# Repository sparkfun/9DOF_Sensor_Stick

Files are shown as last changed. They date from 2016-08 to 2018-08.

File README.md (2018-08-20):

SparkFun 9 Degrees of Freedom - Sensor Stick
=============================================

SparkFun 9 Degrees of Freedom - Sensor Stick

[*SparkFun 9 Degrees of Freedom - Sensor Stick (SEN-13944)*](https://www.sparkfun.com/products/13944)

The SparkFun 9DOF Sensor Stick is a very small sensor board with 9 degrees of freedom.
It includes the LSM9DS1 with a simple I2C interface and a mounting hole for attaching it to your project.
Also, the board is a mere 0.9" in length, 0.4" in width, and 0.036" thick (0.093" overall), allowing it to be easily mounted in just about any application.
 
 Repository Contents
-------------------
* **/Hardware** - All Eagle design files (.brd, .sch)

Documentation
--------------

* **[Installing an Arduino Library Guide](https://learn.sparkfun.com/tutorials/installing-an-arduino-library)** - Basic information on how to install an Arduino library.
* **[Library](https://github.com/sparkfun/SparkFun_LSM9DS1_Arduino_Library)** - Arduino library for the 9DoF Sensor Stick.
* **[Hookup Guide](https://learn.sparkfun.com/tutorials/9dof-sensor-stick-hookup-guide)** - Basic hookup guide for the 9DoF Sensor Stick.
 
License Information
-------------------
The hardware is released under [Creative Commons ShareAlike 4.0 International](https://creativecommons.org/licenses/by-sa/4.0/).
The code is beerware; if you see me (or any other SparkFun employee) at the local, and you've found our code helpful, please buy us a round!

Distributed as-is; no warranty is given.

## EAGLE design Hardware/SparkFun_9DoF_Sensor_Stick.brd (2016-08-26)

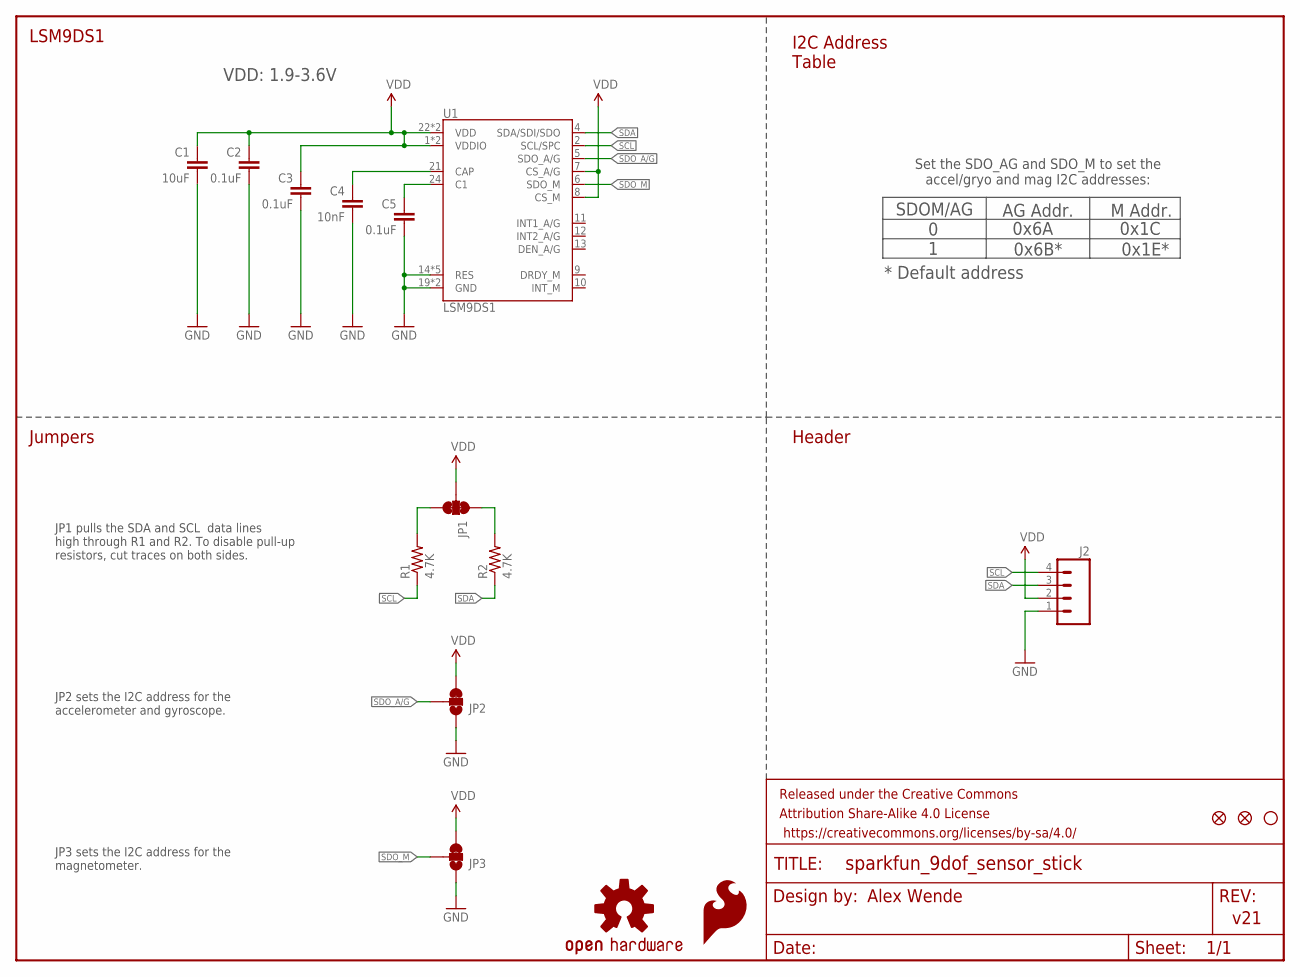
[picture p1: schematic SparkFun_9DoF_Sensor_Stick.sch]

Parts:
C1: 10uF; 0603-CAP
C2, C3, C5: 0.1uF; 0603-CAP
C4: 10nF; 0603-CAP
FD3, FD4: FIDUCIALUFIDUCIAL; MICRO-FIDUCIAL
FRAME1: FRAME-LETTER; CREATIVE_COMMONS
H1: STAND-OFF
J2: M04NO_SILK_ALL_ROUND; 1X04_NO_SILK_ALL_ROUND
JP1: JUMPER-PAD-3-NC_BY_TRACE; PAD-JUMPER-3-3OF3_NC_BY_TRACE_YES_SILK_FULL_BOX
JP2, JP3: JUMPER-PAD-3-2OF3_NC_BY_TRACE_SMALL; PAD-JUMPER-3-2OF3_NC_BY_TRACE_YES_SILK_FULL_BOX
LOGO1: SFE_LOGO_FLAME.1_INCH; SFE_LOGO_FLAME_.1
LOGO3: OSHW-LOGOMINI; OSHW-LOGO-MINI
R1, R2: 4.7K; 0603-RES
U1: LSM9DS1; LGA24-8X4

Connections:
GND: C1.2, C2.2, C3.2, C4.2, C5.2, J2.1, JP2.1, JP3.1, U1.14 (RES), U1.15 (RES), U1.16 (RES), U1.17 (RES), U1.18 (RES), U1.19 (GND), U1.20 (GND)
unnamed: JP1.1, R2.2
unnamed: JP1.3, R1.2
unnamed: C4.1, U1.21 (CAP)
unnamed: C5.1, U1.24 (C1)
SCL: J2.4, R1.1, U1.2 (SCL/SPC)
SDA: J2.3, R2.1, U1.4 (SDA/SDI/SDO)
SDO_A/G: JP2.2, U1.5 (SDO_A/G)
SDO_M: JP3.2, U1.6 (SDO_M)
VDD: C1.1, C2.1, C3.1, J2.2, JP1.2, JP2.3, JP3.3, U1.1 (VDDIO), U1.3 (VDDIO), U1.7 (CS_A/G), U1.8 (CS_M), U1.22 (VDD), U1.23 (VDD)

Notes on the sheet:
Alex Wende
v21
LSM9DS1
SDOM/AG
AG Addr.
0 1
M Addr.
Set the SDO_AG and SDO_M to set the accel/gryo and mag I2C addresses:
I2C Address Table
Header
Jumpers
JP1 pulls the SDA and SCL data lines high through R1 and R2. To disable pull-up resistors, cut traces on both sides.
JP2 sets the I2C address for the accelerometer and gyroscope.
JP3 sets the I2C address for the magnetometer.
0x6A
0x6B*
0x1C
0x1E*
* Default address
VDD: 1.9-3.6V

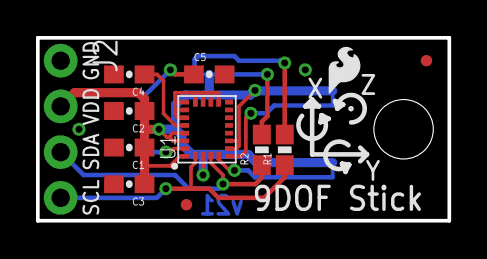
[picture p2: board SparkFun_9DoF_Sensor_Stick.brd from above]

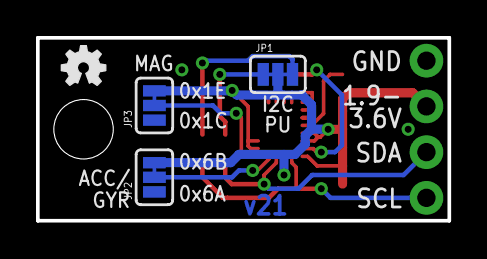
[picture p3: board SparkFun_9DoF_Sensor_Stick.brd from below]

Board: 2 copper layers, 22.9 x 10.2 mm, 18 parts (4 on the bottom side), 10 nets.

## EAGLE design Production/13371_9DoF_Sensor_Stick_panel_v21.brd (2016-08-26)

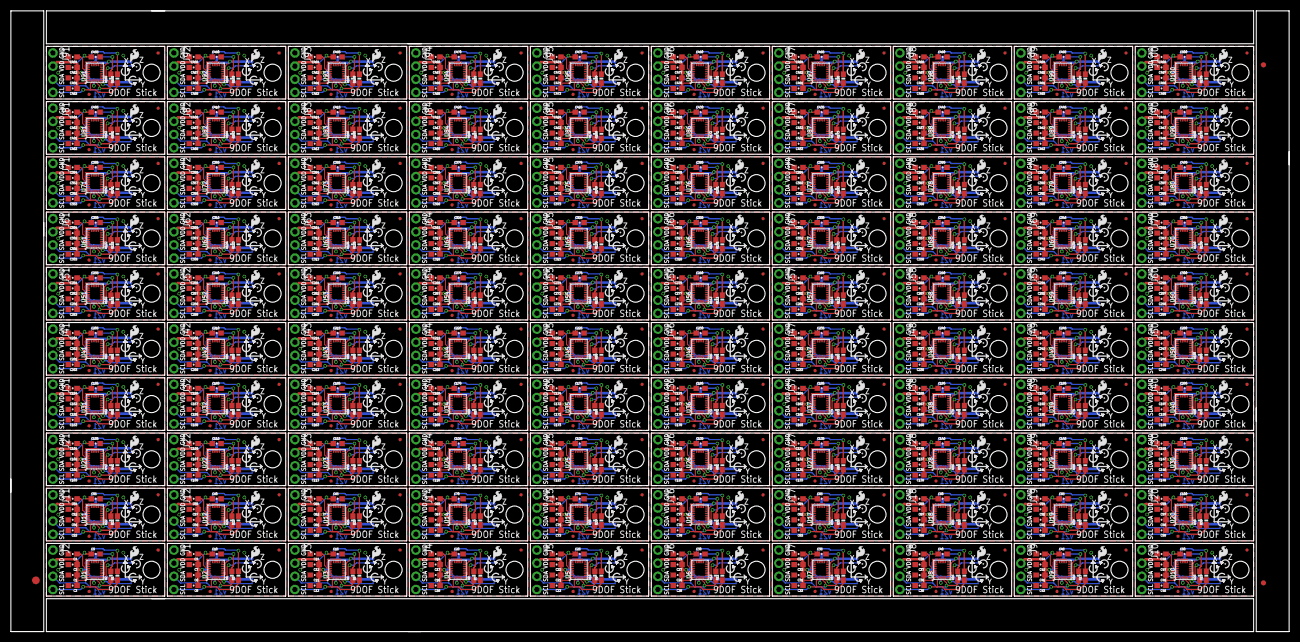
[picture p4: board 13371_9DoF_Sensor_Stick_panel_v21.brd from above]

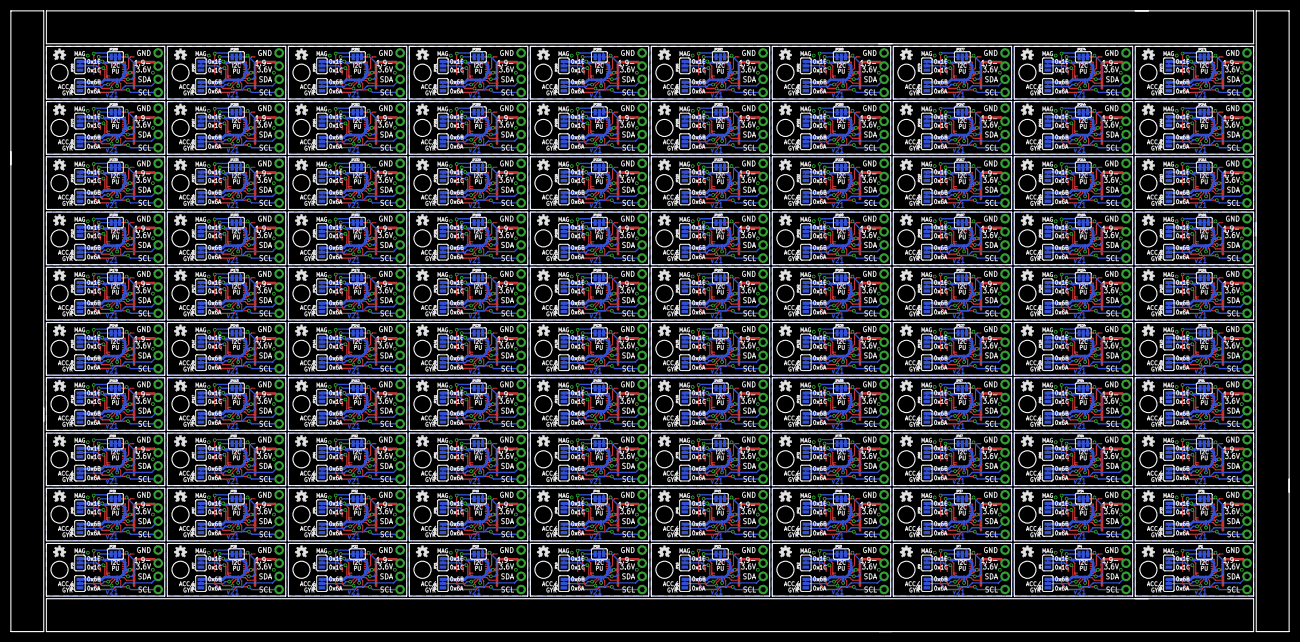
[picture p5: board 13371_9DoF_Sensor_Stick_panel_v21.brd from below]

Board: 2 copper layers, 246.9 x 119.9 mm, 1703 parts (400 on the bottom side), 1000 nets.

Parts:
C1, C6, C11, C16, C21, C26, C31, C36, C41, C46, C51, C56, C61, C66, C71, C76, C81, C86, C91, C96, C101, C106, C111, C116, C121, C126, C131, C136, C141, C146, C151, C156, C161, C166, C171, C176, C181, C186, C191, C196, C201, C206, C211, C216, C221, C226, C231, C236, C241, C246, C251, C256, C261, C266, C271, C276, C281, C286, C291, C296, C301, C306, C311, C316, C321, C326, C331, C336, C341, C346, C351, C356, C361, C366, C371, C376, C381, C386, C391, C396, C401, C406, C411, C416, C421, C426, C431, C436, C441, C446, C451, C456, C461, C466, C471, C476, C481, C486, C491, C496: 10uF; 0603-CAP
C2, C3, C5, C7, C8, C10, C12, C13, C15, C17, C18, C20, C22, C23, C25, C27, C28, C30, C32, C33, C35, C37, C38, C40, C42, C43, C45, C47, C48, C50, C52, C53, C55, C57, C58, C60, C62, C63, C65, C67, C68, C70, C72, C73, C75, C77, C78, C80, C82, C83, C85, C87, C88, C90, C92, C93, C95, C97, C98, C100, C102, C103, C105, C107, C108, C110, C112, C113, C115, C117, C118, C120, C122, C123, C125, C127, C128, C130, C132, C133, C135, C137, C138, C140, C142, C143, C145, C147, C148, C150, C152, C153, C155, C157, C158, C160, C162, C163, C165, C167, C168, C170, C172, C173, C175, C177, C178, C180, C182, C183, C185, C187, C188, C190, C192, C193, C195, C197, C198, C200, C202, C203, C205, C207, C208, C210, C212, C213, C215, C217, C218, C220, C222, C223, C225, C227, C228, C230, C232, C233, C235, C237, C238, C240, C242, C243, C245, C247, C248, C250, C252, C253, C255, C257, C258, C260, C262, C263, C265, C267, C268, C270, C272, C273, C275, C277, C278, C280, C282, C283, C285, C287, C288, C290, C292, C293, C295, C297, C298, C300, C302, C303, C305, C307, C308, C310, C312, C313, C315, C317, C318, C320, C322, C323, C325, C327, C328, C330, C332, C333, C335, C337, C338, C340, C342, C343, C345, C347, C348, C350, C352, C353, C355, C357, C358, C360, C362, C363, C365, C367, C368, C370, C372, C373, C375, C377, C378, C380, C382, C383, C385, C387, C388, C390, C392, C393, C395, C397, C398, C400, C402, C403, C405, C407, C408, C410, C412, C413, C415, C417, C418, C420, C422, C423, C425, C427, C428, C430, C432, C433, C435, C437, C438, C440, C442, C443, C445, C447, C448, C450, C452, C453, C455, C457, C458, C460, C462, C463, C465, C467, C468, C470, C472, C473, C475, C477, C478, C480, C482, C483, C485, C487, C488, C490, C492, C493, C495, C497, C498, C500: 0.1uF; 0603-CAP
C4, C9, C14, C19, C24, C29, C34, C39, C44, C49, C54, C59, C64, C69, C74, C79, C84, C89, C94, C99, C104, C109, C114, C119, C124, C129, C134, C139, C144, C149, C154, C159, C164, C169, C174, C179, C184, C189, C194, C199, C204, C209, C214, C219, C224, C229, C234, C239, C244, C249, C254, C259, C264, C269, C274, C279, C284, C289, C294, C299, C304, C309, C314, C319, C324, C329, C334, C339, C344, C349, C354, C359, C364, C369, C374, C379, C384, C389, C394, C399, C404, C409, C414, C419, C424, C429, C434, C439, C444, C449, C454, C459, C464, C469, C474, C479, C484, C489, C494, C499: 10nF; 0603-CAP
E$1: FIDUCIAL-1.5X3
E$7, E$8: FIDUCIAL-1X2
FD1, FD2, FD3, FD4, FD5, FD6, FD7, FD8, FD9, FD10, FD11, FD12, FD13, FD14, FD15, FD16, FD17, FD18, FD19, FD20, FD21, FD22, FD23, FD24, FD25, FD26, FD27, FD28, FD29, FD30, FD31, FD32, FD33, FD34, FD35, FD36, FD37, FD38, FD39, FD40, FD41, FD42, FD43, FD44, FD45, FD46, FD47, FD48, FD49, FD50, FD51, FD52, FD53, FD54, FD55, FD56, FD57, FD58, FD59, FD60, FD61, FD62, FD63, FD64, FD65, FD66, FD67, FD68, FD69, FD70, FD71, FD72, FD73, FD74, FD75, FD76, FD77, FD78, FD79, FD80, FD81, FD82, FD83, FD84, FD85, FD86, FD87, FD88, FD89, FD90, FD91, FD92, FD93, FD94, FD95, FD96, FD97, FD98, FD99, FD100, FD101, FD102, FD103, FD104, FD105, FD106, FD107, FD108, FD109, FD110, FD111, FD112, FD113, FD114, FD115, FD116, FD117, FD118, FD119, FD120, FD121, FD122, FD123, FD124, FD125, FD126, FD127, FD128, FD129, FD130, FD131, FD132, FD133, FD134, FD135, FD136, FD137, FD138, FD139, FD140, FD141, FD142, FD143, FD144, FD145, FD146, FD147, FD148, FD149, FD150, FD151, FD152, FD153, FD154, FD155, FD156, FD157, FD158, FD159, FD160, FD161, FD162, FD163, FD164, FD165, FD166, FD167, FD168, FD169, FD170, FD171, FD172, FD173, FD174, FD175, FD176, FD177, FD178, FD179, FD180, FD181, FD182, FD183, FD184, FD185, FD186, FD187, FD188, FD189, FD190, FD191, FD192, FD193, FD194, FD195, FD196, FD197, FD198, FD199, FD200: FIDUCIALUFIDUCIAL; MICRO-FIDUCIAL
H1, H2, H3, H4, H5, H6, H7, H8, H9, H10, H11, H12, H13, H14, H15, H16, H17, H18, H19, H20, H21, H22, H23, H24, H25, H26, H27, H28, H29, H30, H31, H32, H33, H34, H35, H36, H37, H38, H39, H40, H41, H42, H43, H44, H45, H46, H47, H48, H49, H50, H51, H52, H53, H54, H55, H56, H57, H58, H59, H60, H61, H62, H63, H64, H65, H66, H67, H68, H69, H70, H71, H72, H73, H74, H75, H76, H77, H78, H79, H80, H81, H82, H83, H84, H85, H86, H87, H88, H89, H90, H91, H92, H93, H94, H95, H96, H97, H98, H99, H100: STAND-OFF
J1, J2, J3, J4, J5, J6, J7, J8, J9, J10, J11, J12, J13, J14, J15, J16, J17, J18, J19, J20, J21, J22, J23, J24, J25, J26, J27, J28, J29, J30, J31, J32, J33, J34, J35, J36, J37, J38, J39, J40, J41, J42, J43, J44, J45, J46, J47, J48, J49, J50, J51, J52, J53, J54, J55, J56, J57, J58, J59, J60, J61, J62, J63, J64, J65, J66, J67, J68, J69, J70, J71, J72, J73, J74, J75, J76, J77, J78, J79, J80, J81, J82, J83, J84, J85, J86, J87, J88, J89, J90, J91, J92, J93, J94, J95, J96, J97, J98, J99, J100: 1X04_NO_SILK_ALL_ROUND
JP1, JP4, JP7, JP10, JP13, JP16, JP19, JP22, JP25, JP28, JP31, JP34, JP37, JP40, JP43, JP46, JP49, JP52, JP55, JP58, JP61, JP64, JP67, JP70, JP73, JP76, JP79, JP82, JP85, JP88, JP91, JP94, JP97, JP100, JP103, JP106, JP109, JP112, JP115, JP118, JP121, JP124, JP127, JP130, JP133, JP136, JP139, JP142, JP145, JP148, JP151, JP154, JP157, JP160, JP163, JP166, JP169, JP172, JP175, JP178, JP181, JP184, JP187, JP190, JP193, JP196, JP199, JP202, JP205, JP208, JP211, JP214, JP217, JP220, JP223, JP226, JP229, JP232, JP235, JP238, JP241, JP244, JP247, JP250, JP253, JP256, JP259, JP262, JP265, JP268, JP271, JP274, JP277, JP280, JP283, JP286, JP289, JP292, JP295, JP298: PAD-JUMPER-3-3OF3_NC_BY_TRACE_YES_SILK_FULL_BOX
JP2, JP3, JP5, JP6, JP8, JP9, JP11, JP12, JP14, JP15, JP17, JP18, JP20, JP21, JP23, JP24, JP26, JP27, JP29, JP30, JP32, JP33, JP35, JP36, JP38, JP39, JP41, JP42, JP44, JP45, JP47, JP48, JP50, JP51, JP53, JP54, JP56, JP57, JP59, JP60, JP62, JP63, JP65, JP66, JP68, JP69, JP71, JP72, JP74, JP75, JP77, JP78, JP80, JP81, JP83, JP84, JP86, JP87, JP89, JP90, JP92, JP93, JP95, JP96, JP98, JP99, JP101, JP102, JP104, JP105, JP107, JP108, JP110, JP111, JP113, JP114, JP116, JP117, JP119, JP120, JP122, JP123, JP125, JP126, JP128, JP129, JP131, JP132, JP134, JP135, JP137, JP138, JP140, JP141, JP143, JP144, JP146, JP147, JP149, JP150, JP152, JP153, JP155, JP156, JP158, JP159, JP161, JP162, JP164, JP165, JP167, JP168, JP170, JP171, JP173, JP174, JP176, JP177, JP179, JP180, JP182, JP183, JP185, JP186, JP188, JP189, JP191, JP192, JP194, JP195, JP197, JP198, JP200, JP201, JP203, JP204, JP206, JP207, JP209, JP210, JP212, JP213, JP215, JP216, JP218, JP219, JP221, JP222, JP224, JP225, JP227, JP228, JP230, JP231, JP233, JP234, JP236, JP237, JP239, JP240, JP242, JP243, JP245, JP246, JP248, JP249, JP251, JP252, JP254, JP255, JP257, JP258, JP260, JP261, JP263, JP264, JP266, JP267, JP269, JP270, JP272, JP273, JP275, JP276, JP278, JP279, JP281, JP282, JP284, JP285, JP287, JP288, JP290, JP291, JP293, JP294, JP296, JP297, JP299, JP300: PAD-JUMPER-3-2OF3_NC_BY_TRACE_YES_SILK_FULL_BOX
LOGO1, LOGO2, LOGO5, LOGO7, LOGO9, LOGO11, LOGO13, LOGO15, LOGO17, LOGO19, LOGO21, LOGO23, LOGO25, LOGO27, LOGO29, LOGO31, LOGO33, LOGO35, LOGO37, LOGO39, LOGO41, LOGO43, LOGO45, LOGO47, LOGO49, LOGO51, LOGO53, LOGO55, LOGO57, LOGO59, LOGO61, LOGO63, LOGO65, LOGO67, LOGO69, LOGO71, LOGO73, LOGO75, LOGO77, LOGO79, LOGO81, LOGO83, LOGO85, LOGO87, LOGO89, LOGO91, LOGO93, LOGO95, LOGO97, LOGO99, LOGO101, LOGO103, LOGO105, LOGO107, LOGO109, LOGO111, LOGO113, LOGO115, LOGO117, LOGO119, LOGO121, LOGO123, LOGO125, LOGO127, LOGO129, LOGO131, LOGO133, LOGO135, LOGO137, LOGO139, LOGO141, LOGO143, LOGO145, LOGO147, LOGO149, LOGO151, LOGO153, LOGO155, LOGO157, LOGO159, LOGO161, LOGO163, LOGO165, LOGO167, LOGO169, LOGO171, LOGO173, LOGO175, LOGO177, LOGO179, LOGO181, LOGO183, LOGO185, LOGO187, LOGO189, LOGO191, LOGO193, LOGO195, LOGO197, LOGO199: SFE_LOGO_FLAME.1_INCH; SFE_LOGO_FLAME_.1
LOGO3, LOGO4, LOGO6, LOGO8, LOGO10, LOGO12, LOGO14, LOGO16, LOGO18, LOGO20, LOGO22, LOGO24, LOGO26, LOGO28, LOGO30, LOGO32, LOGO34, LOGO36, LOGO38, LOGO40, LOGO42, LOGO44, LOGO46, LOGO48, LOGO50, LOGO52, LOGO54, LOGO56, LOGO58, LOGO60, LOGO62, LOGO64, LOGO66, LOGO68, LOGO70, LOGO72, LOGO74, LOGO76, LOGO78, LOGO80, LOGO82, LOGO84, LOGO86, LOGO88, LOGO90, LOGO92, LOGO94, LOGO96, LOGO98, LOGO100, LOGO102, LOGO104, LOGO106, LOGO108, LOGO110, LOGO112, LOGO114, LOGO116, LOGO118, LOGO120, LOGO122, LOGO124, LOGO126, LOGO128, LOGO130, LOGO132, LOGO134, LOGO136, LOGO138, LOGO140, LOGO142, LOGO144, LOGO146, LOGO148, LOGO150, LOGO152, LOGO154, LOGO156, LOGO158, LOGO160, LOGO162, LOGO164, LOGO166, LOGO168, LOGO170, LOGO172, LOGO174, LOGO176, LOGO178, LOGO180, LOGO182, LOGO184, LOGO186, LOGO188, LOGO190, LOGO192, LOGO194, LOGO196, LOGO198, LOGO200: OSHW-LOGOMINI; OSHW-LOGO-MINI
R1, R2, R3, R4, R5, R6, R7, R8, R9, R10, R11, R12, R13, R14, R15, R16, R17, R18, R19, R20, R21, R22, R23, R24, R25, R26, R27, R28, R29, R30, R31, R32, R33, R34, R35, R36, R37, R38, R39, R40, R41, R42, R43, R44, R45, R46, R47, R48, R49, R50, R51, R52, R53, R54, R55, R56, R57, R58, R59, R60, R61, R62, R63, R64, R65, R66, R67, R68, R69, R70, R71, R72, R73, R74, R75, R76, R77, R78, R79, R80, R81, R82, R83, R84, R85, R86, R87, R88, R89, R90, R91, R92, R93, R94, R95, R96, R97, R98, R99, R100, R101, R102, R103, R104, R105, R106, R107, R108, R109, R110, R111, R112, R113, R114, R115, R116, R117, R118, R119, R120, R121, R122, R123, R124, R125, R126, R127, R128, R129, R130, R131, R132, R133, R134, R135, R136, R137, R138, R139, R140, R141, R142, R143, R144, R145, R146, R147, R148, R149, R150, R151, R152, R153, R154, R155, R156, R157, R158, R159, R160, R161, R162, R163, R164, R165, R166, R167, R168, R169, R170, R171, R172, R173, R174, R175, R176, R177, R178, R179, R180, R181, R182, R183, R184, R185, R186, R187, R188, R189, R190, R191, R192, R193, R194, R195, R196, R197, R198, R199, R200: 4.7K; 0603-RES
U1, U2, U3, U4, U5, U6, U7, U8, U9, U10, U11, U12, U13, U14, U15, U16, U17, U18, U19, U20, U21, U22, U23, U24, U25, U26, U27, U28, U29, U30, U31, U32, U33, U34, U35, U36, U37, U38, U39, U40, U41, U42, U43, U44, U45, U46, U47, U48, U49, U50, U51, U52, U53, U54, U55, U56, U57, U58, U59, U60, U61, U62, U63, U64, U65, U66, U67, U68, U69, U70, U71, U72, U73, U74, U75, U76, U77, U78, U79, U80, U81, U82, U83, U84, U85, U86, U87, U88, U89, U90, U91, U92, U93, U94, U95, U96, U97, U98, U99, U100: LSM9DS1; LGA24-8X4

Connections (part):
GND: C1.2, C2.2, C3.2, C4.2, C5.2, J2.1, JP2.1, JP3.1, U1.14, U1.15, U1.16, U1.17, U1.18, U1.19, U1.20
GND1: C6.2, C7.2, C8.2, C9.2, C10.2, J1.1, JP5.1, JP6.1, U2.14, U2.15, U2.16, U2.17, U2.18, U2.19, U2.20
GND2: C11.2, C12.2, C13.2, C14.2, C15.2, J3.1, JP8.1, JP9.1, U3.14, U3.15, U3.16, U3.17, U3.18, U3.19, U3.20
GND3: C16.2, C17.2, C18.2, C19.2, C20.2, J4.1, JP11.1, JP12.1, U4.14, U4.15, U4.16, U4.17, U4.18, U4.19, U4.20
GND4: C21.2, C22.2, C23.2, C24.2, C25.2, J5.1, JP14.1, JP15.1, U5.14, U5.15, U5.16, U5.17, U5.18, U5.19, U5.20
GND5: C26.2, C27.2, C28.2, C29.2, C30.2, J6.1, JP17.1, JP18.1, U6.14, U6.15, U6.16, U6.17, U6.18, U6.19, U6.20
GND6: C31.2, C32.2, C33.2, C34.2, C35.2, J7.1, JP20.1, JP21.1, U7.14, U7.15, U7.16, U7.17, U7.18, U7.19, U7.20
GND7: C36.2, C37.2, C38.2, C39.2, C40.2, J8.1, JP23.1, JP24.1, U8.14, U8.15, U8.16, U8.17, U8.18, U8.19, U8.20
GND8: C41.2, C42.2, C43.2, C44.2, C45.2, J9.1, JP26.1, JP27.1, U9.14, U9.15, U9.16, U9.17, U9.18, U9.19, U9.20
GND9: C46.2, C47.2, C48.2, C49.2, C50.2, J10.1, JP29.1, JP30.1, U10.14, U10.15, U10.16, U10.17, U10.18, U10.19, U10.20
GND10: C51.2, C52.2, C53.2, C54.2, C55.2, J11.1, JP32.1, JP33.1, U11.14, U11.15, U11.16, U11.17, U11.18, U11.19, U11.20
GND11: C56.2, C57.2, C58.2, C59.2, C60.2, J12.1, JP35.1, JP36.1, U12.14, U12.15, U12.16, U12.17, U12.18, U12.19, U12.20
GND12: C61.2, C62.2, C63.2, C64.2, C65.2, J13.1, JP38.1, JP39.1, U13.14, U13.15, U13.16, U13.17, U13.18, U13.19, U13.20
GND13: C66.2, C67.2, C68.2, C69.2, C70.2, J14.1, JP41.1, JP42.1, U14.14, U14.15, U14.16, U14.17, U14.18, U14.19, U14.20
GND14: C71.2, C72.2, C73.2, C74.2, C75.2, J15.1, JP44.1, JP45.1, U15.14, U15.15, U15.16, U15.17, U15.18, U15.19, U15.20
GND15: C76.2, C77.2, C78.2, C79.2, C80.2, J16.1, JP47.1, JP48.1, U16.14, U16.15, U16.16, U16.17, U16.18, U16.19, U16.20
GND16: C81.2, C82.2, C83.2, C84.2, C85.2, J17.1, JP50.1, JP51.1, U17.14, U17.15, U17.16, U17.17, U17.18, U17.19, U17.20
GND17: C86.2, C87.2, C88.2, C89.2, C90.2, J18.1, JP53.1, JP54.1, U18.14, U18.15, U18.16, U18.17, U18.18, U18.19, U18.20
GND18: C91.2, C92.2, C93.2, C94.2, C95.2, J19.1, JP56.1, JP57.1, U19.14, U19.15, U19.16, U19.17, U19.18, U19.19, U19.20
GND19: C96.2, C97.2, C98.2, C99.2, C100.2, J20.1, JP59.1, JP60.1, U20.14, U20.15, U20.16, U20.17, U20.18, U20.19, U20.20
GND20: C101.2, C102.2, C103.2, C104.2, C105.2, J21.1, JP62.1, JP63.1, U21.14, U21.15, U21.16, U21.17, U21.18, U21.19, U21.20
GND21: C106.2, C107.2, C108.2, C109.2, C110.2, J22.1, JP65.1, JP66.1, U22.14, U22.15, U22.16, U22.17, U22.18, U22.19, U22.20
GND22: C111.2, C112.2, C113.2, C114.2, C115.2, J23.1, JP68.1, JP69.1, U23.14, U23.15, U23.16, U23.17, U23.18, U23.19, U23.20
GND23: C116.2, C117.2, C118.2, C119.2, C120.2, J24.1, JP71.1, JP72.1, U24.14, U24.15, U24.16, U24.17, U24.18, U24.19, U24.20
GND24: C121.2, C122.2, C123.2, C124.2, C125.2, J25.1, JP74.1, JP75.1, U25.14, U25.15, U25.16, U25.17, U25.18, U25.19, U25.20
GND25: C126.2, C127.2, C128.2, C129.2, C130.2, J26.1, JP77.1, JP78.1, U26.14, U26.15, U26.16, U26.17, U26.18, U26.19, U26.20
GND26: C131.2, C132.2, C133.2, C134.2, C135.2, J27.1, JP80.1, JP81.1, U27.14, U27.15, U27.16, U27.17, U27.18, U27.19, U27.20
GND27: C136.2, C137.2, C138.2, C139.2, C140.2, J28.1, JP83.1, JP84.1, U28.14, U28.15, U28.16, U28.17, U28.18, U28.19, U28.20
GND28: C141.2, C142.2, C143.2, C144.2, C145.2, J29.1, JP86.1, JP87.1, U29.14, U29.15, U29.16, U29.17, U29.18, U29.19, U29.20
GND29: C146.2, C147.2, C148.2, C149.2, C150.2, J30.1, JP89.1, JP90.1, U30.14, U30.15, U30.16, U30.17, U30.18, U30.19, U30.20
GND30: C151.2, C152.2, C153.2, C154.2, C155.2, J31.1, JP92.1, JP93.1, U31.14, U31.15, U31.16, U31.17, U31.18, U31.19, U31.20
GND31: C156.2, C157.2, C158.2, C159.2, C160.2, J32.1, JP95.1, JP96.1, U32.14, U32.15, U32.16, U32.17, U32.18, U32.19, U32.20
GND32: C161.2, C162.2, C163.2, C164.2, C165.2, J33.1, JP98.1, JP99.1, U33.14, U33.15, U33.16, U33.17, U33.18, U33.19, U33.20
GND33: C166.2, C167.2, C168.2, C169.2, C170.2, J34.1, JP101.1, JP102.1, U34.14, U34.15, U34.16, U34.17, U34.18, U34.19, U34.20
GND34: C171.2, C172.2, C173.2, C174.2, C175.2, J35.1, JP104.1, JP105.1, U35.14, U35.15, U35.16, U35.17, U35.18, U35.19, U35.20
GND35: C176.2, C177.2, C178.2, C179.2, C180.2, J36.1, JP107.1, JP108.1, U36.14, U36.15, U36.16, U36.17, U36.18, U36.19, U36.20
GND36: C181.2, C182.2, C183.2, C184.2, C185.2, J37.1, JP110.1, JP111.1, U37.14, U37.15, U37.16, U37.17, U37.18, U37.19, U37.20
GND37: C186.2, C187.2, C188.2, C189.2, C190.2, J38.1, JP113.1, JP114.1, U38.14, U38.15, U38.16, U38.17, U38.18, U38.19, U38.20
GND38: C191.2, C192.2, C193.2, C194.2, C195.2, J39.1, JP116.1, JP117.1, U39.14, U39.15, U39.16, U39.17, U39.18, U39.19, U39.20
GND39: C196.2, C197.2, C198.2, C199.2, C200.2, J40.1, JP119.1, JP120.1, U40.14, U40.15, U40.16, U40.17, U40.18, U40.19, U40.20
GND40: C201.2, C202.2, C203.2, C204.2, C205.2, J41.1, JP122.1, JP123.1, U41.14, U41.15, U41.16, U41.17, U41.18, U41.19, U41.20
GND41: C206.2, C207.2, C208.2, C209.2, C210.2, J42.1, JP125.1, JP126.1, U42.14, U42.15, U42.16, U42.17, U42.18, U42.19, U42.20
GND42: C211.2, C212.2, C213.2, C214.2, C215.2, J43.1, JP128.1, JP129.1, U43.14, U43.15, U43.16, U43.17, U43.18, U43.19, U43.20
GND43: C216.2, C217.2, C218.2, C219.2, C220.2, J44.1, JP131.1, JP132.1, U44.14, U44.15, U44.16, U44.17, U44.18, U44.19, U44.20
GND44: C221.2, C222.2, C223.2, C224.2, C225.2, J45.1, JP134.1, JP135.1, U45.14, U45.15, U45.16, U45.17, U45.18, U45.19, U45.20
GND45: C226.2, C227.2, C228.2, C229.2, C230.2, J46.1, JP137.1, JP138.1, U46.14, U46.15, U46.16, U46.17, U46.18, U46.19, U46.20
GND46: C231.2, C232.2, C233.2, C234.2, C235.2, J47.1, JP140.1, JP141.1, U47.14, U47.15, U47.16, U47.17, U47.18, U47.19, U47.20
GND47: C236.2, C237.2, C238.2, C239.2, C240.2, J48.1, JP143.1, JP144.1, U48.14, U48.15, U48.16, U48.17, U48.18, U48.19, U48.20
GND48: C241.2, C242.2, C243.2, C244.2, C245.2, J49.1, JP146.1, JP147.1, U49.14, U49.15, U49.16, U49.17, U49.18, U49.19, U49.20
GND49: C246.2, C247.2, C248.2, C249.2, C250.2, J50.1, JP149.1, JP150.1, U50.14, U50.15, U50.16, U50.17, U50.18, U50.19, U50.20
GND50: C251.2, C252.2, C253.2, C254.2, C255.2, J51.1, JP152.1, JP153.1, U51.14, U51.15, U51.16, U51.17, U51.18, U51.19, U51.20
GND51: C256.2, C257.2, C258.2, C259.2, C260.2, J52.1, JP155.1, JP156.1, U52.14, U52.15, U52.16, U52.17, U52.18, U52.19, U52.20
GND52: C261.2, C262.2, C263.2, C264.2, C265.2, J53.1, JP158.1, JP159.1, U53.14, U53.15, U53.16, U53.17, U53.18, U53.19, U53.20
GND53: C266.2, C267.2, C268.2, C269.2, C270.2, J54.1, JP161.1, JP162.1, U54.14, U54.15, U54.16, U54.17, U54.18, U54.19, U54.20
GND54: C271.2, C272.2, C273.2, C274.2, C275.2, J55.1, JP164.1, JP165.1, U55.14, U55.15, U55.16, U55.17, U55.18, U55.19, U55.20
GND55: C276.2, C277.2, C278.2, C279.2, C280.2, J56.1, JP167.1, JP168.1, U56.14, U56.15, U56.16, U56.17, U56.18, U56.19, U56.20
GND56: C281.2, C282.2, C283.2, C284.2, C285.2, J57.1, JP170.1, JP171.1, U57.14, U57.15, U57.16, U57.17, U57.18, U57.19, U57.20
GND57: C286.2, C287.2, C288.2, C289.2, C290.2, J58.1, JP173.1, JP174.1, U58.14, U58.15, U58.16, U58.17, U58.18, U58.19, U58.20
GND58: C291.2, C292.2, C293.2, C294.2, C295.2, J59.1, JP176.1, JP177.1, U59.14, U59.15, U59.16, U59.17, U59.18, U59.19, U59.20
GND59: C296.2, C297.2, C298.2, C299.2, C300.2, J60.1, JP179.1, JP180.1, U60.14, U60.15, U60.16, U60.17, U60.18, U60.19, U60.20
GND60: C301.2, C302.2, C303.2, C304.2, C305.2, J61.1, JP182.1, JP183.1, U61.14, U61.15, U61.16, U61.17, U61.18, U61.19, U61.20
GND61: C306.2, C307.2, C308.2, C309.2, C310.2, J62.1, JP185.1, JP186.1, U62.14, U62.15, U62.16, U62.17, U62.18, U62.19, U62.20
GND62: C311.2, C312.2, C313.2, C314.2, C315.2, J63.1, JP188.1, JP189.1, U63.14, U63.15, U63.16, U63.17, U63.18, U63.19, U63.20
GND63: C316.2, C317.2, C318.2, C319.2, C320.2, J64.1, JP191.1, JP192.1, U64.14, U64.15, U64.16, U64.17, U64.18, U64.19, U64.20
GND64: C321.2, C322.2, C323.2, C324.2, C325.2, J65.1, JP194.1, JP195.1, U65.14, U65.15, U65.16, U65.17, U65.18, U65.19, U65.20
GND65: C326.2, C327.2, C328.2, C329.2, C330.2, J66.1, JP197.1, JP198.1, U66.14, U66.15, U66.16, U66.17, U66.18, U66.19, U66.20
GND66: C331.2, C332.2, C333.2, C334.2, C335.2, J67.1, JP200.1, JP201.1, U67.14, U67.15, U67.16, U67.17, U67.18, U67.19, U67.20
GND67: C336.2, C337.2, C338.2, C339.2, C340.2, J68.1, JP203.1, JP204.1, U68.14, U68.15, U68.16, U68.17, U68.18, U68.19, U68.20
GND68: C341.2, C342.2, C343.2, C344.2, C345.2, J69.1, JP206.1, JP207.1, U69.14, U69.15, U69.16, U69.17, U69.18, U69.19, U69.20
GND69: C346.2, C347.2, C348.2, C349.2, C350.2, J70.1, JP209.1, JP210.1, U70.14, U70.15, U70.16, U70.17, U70.18, U70.19, U70.20
GND70: C351.2, C352.2, C353.2, C354.2, C355.2, J71.1, JP212.1, JP213.1, U71.14, U71.15, U71.16, U71.17, U71.18, U71.19, U71.20
GND71: C356.2, C357.2, C358.2, C359.2, C360.2, J72.1, JP215.1, JP216.1, U72.14, U72.15, U72.16, U72.17, U72.18, U72.19, U72.20
GND72: C361.2, C362.2, C363.2, C364.2, C365.2, J73.1, JP218.1, JP219.1, U73.14, U73.15, U73.16, U73.17, U73.18, U73.19, U73.20
GND73: C366.2, C367.2, C368.2, C369.2, C370.2, J74.1, JP221.1, JP222.1, U74.14, U74.15, U74.16, U74.17, U74.18, U74.19, U74.20
GND74: C371.2, C372.2, C373.2, C374.2, C375.2, J75.1, JP224.1, JP225.1, U75.14, U75.15, U75.16, U75.17, U75.18, U75.19, U75.20
GND75: C376.2, C377.2, C378.2, C379.2, C380.2, J76.1, JP227.1, JP228.1, U76.14, U76.15, U76.16, U76.17, U76.18, U76.19, U76.20
GND76: C381.2, C382.2, C383.2, C384.2, C385.2, J77.1, JP230.1, JP231.1, U77.14, U77.15, U77.16, U77.17, U77.18, U77.19, U77.20
GND77: C386.2, C387.2, C388.2, C389.2, C390.2, J78.1, JP233.1, JP234.1, U78.14, U78.15, U78.16, U78.17, U78.18, U78.19, U78.20
GND78: C391.2, C392.2, C393.2, C394.2, C395.2, J79.1, JP236.1, JP237.1, U79.14, U79.15, U79.16, U79.17, U79.18, U79.19, U79.20
GND79: C396.2, C397.2, C398.2, C399.2, C400.2, J80.1, JP239.1, JP240.1, U80.14, U80.15, U80.16, U80.17, U80.18, U80.19, U80.20
GND80: C401.2, C402.2, C403.2, C404.2, C405.2, J81.1, JP242.1, JP243.1, U81.14, U81.15, U81.16, U81.17, U81.18, U81.19, U81.20
GND81: C406.2, C407.2, C408.2, C409.2, C410.2, J82.1, JP245.1, JP246.1, U82.14, U82.15, U82.16, U82.17, U82.18, U82.19, U82.20
GND82: C411.2, C412.2, C413.2, C414.2, C415.2, J83.1, JP248.1, JP249.1, U83.14, U83.15, U83.16, U83.17, U83.18, U83.19, U83.20
GND83: C416.2, C417.2, C418.2, C419.2, C420.2, J84.1, JP251.1, JP252.1, U84.14, U84.15, U84.16, U84.17, U84.18, U84.19, U84.20
GND84: C421.2, C422.2, C423.2, C424.2, C425.2, J85.1, JP254.1, JP255.1, U85.14, U85.15, U85.16, U85.17, U85.18, U85.19, U85.20
GND85: C426.2, C427.2, C428.2, C429.2, C430.2, J86.1, JP257.1, JP258.1, U86.14, U86.15, U86.16, U86.17, U86.18, U86.19, U86.20
GND86: C431.2, C432.2, C433.2, C434.2, C435.2, J87.1, JP260.1, JP261.1, U87.14, U87.15, U87.16, U87.17, U87.18, U87.19, U87.20
GND87: C436.2, C437.2, C438.2, C439.2, C440.2, J88.1, JP263.1, JP264.1, U88.14, U88.15, U88.16, U88.17, U88.18, U88.19, U88.20
GND88: C441.2, C442.2, C443.2, C444.2, C445.2, J89.1, JP266.1, JP267.1, U89.14, U89.15, U89.16, U89.17, U89.18, U89.19, U89.20
GND89: C446.2, C447.2, C448.2, C449.2, C450.2, J90.1, JP269.1, JP270.1, U90.14, U90.15, U90.16, U90.17, U90.18, U90.19, U90.20
GND90: C451.2, C452.2, C453.2, C454.2, C455.2, J91.1, JP272.1, JP273.1, U91.14, U91.15, U91.16, U91.17, U91.18, U91.19, U91.20
GND91: C456.2, C457.2, C458.2, C459.2, C460.2, J92.1, JP275.1, JP276.1, U92.14, U92.15, U92.16, U92.17, U92.18, U92.19, U92.20
GND92: C461.2, C462.2, C463.2, C464.2, C465.2, J93.1, JP278.1, JP279.1, U93.14, U93.15, U93.16, U93.17, U93.18, U93.19, U93.20
GND93: C466.2, C467.2, C468.2, C469.2, C470.2, J94.1, JP281.1, JP282.1, U94.14, U94.15, U94.16, U94.17, U94.18, U94.19, U94.20
GND94: C471.2, C472.2, C473.2, C474.2, C475.2, J95.1, JP284.1, JP285.1, U95.14, U95.15, U95.16, U95.17, U95.18, U95.19, U95.20
GND95: C476.2, C477.2, C478.2, C479.2, C480.2, J96.1, JP287.1, JP288.1, U96.14, U96.15, U96.16, U96.17, U96.18, U96.19, U96.20
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

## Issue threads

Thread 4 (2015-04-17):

JP3 should be named JP1

SFE-KADE, 2015-04-17:

ToniCorinne, 2015-04-17:
So, fiducials, the logo, standoffs are all JP prefixes. Because of this, JP3 is actually JP3. Do we need to update all of those other prefixes to something else if we are not to use JP# for those then?

SFE-KADE, 2015-04-20:
I'd swap the names for the fiducial named JP1 and the header named JP3 since the names for the standoffs or fiducials don't appear by default and won't be present in the pdf version of the schematic. The rest of the names can stay the same. It'll make more sense/look cleaner with that header named JP1.

mgrusin, 2015-04-20:
At some point can we change the default designation for fiducials etc. to
something other than JP? It causes a lot of dumb problems like this. Since
it doesn't show up it could be FIDx, LOGOx, MIKEx etc.

-Mike Grusin
SparkFun Electronics
303 284-0979 x 405
"This is only temporary... unless it works!" -Red Green

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

ToniCorinne, 2015-04-20:
I personally agree with Mike, but I think that's a discussion better fit for the checklist repo perhaps?

Anyway, change was fixed and pushed for this specific board.

Closed 2015-04-20.

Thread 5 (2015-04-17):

Y trace intersection under vreg

SFE-KADE, 2015-04-17:

ToniCorinne, 2015-04-17:
Fixed.

Closed 2015-04-17.

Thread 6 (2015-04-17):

top right ground connection on ITG-3200 needs to be cleaned up

SFE-KADE, 2015-04-17:
One of the two traces isn't actually connected. Need to either remove it or connect it.

ToniCorinne, 2015-04-17:
Connected.

Closed 2015-04-17.

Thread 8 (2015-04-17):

periods in bottom silk labels aren't really needed

SFE-KADE, 2015-04-17:
The periods for abbreviations of address and magnetometer aren't really needed. If you want to keep them you should probably add the period to the gyro and accel labels too for consistency.

ToniCorinne, 2015-04-17:
Standarized.

Closed 2015-04-17.

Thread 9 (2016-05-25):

Eng. Checklist Issues

ericorosel, 2016-05-25:
1) The version number for the design in the "new_rev" repo is v20 while current storefront version is v16. This is an odd situation, this design has attributes of both and new product and a product rev, which makes assigning a version number to the design difficult. I just want to make sure that we increment this design's version numbers properly.

2) There are some seemingly necessary trace width variations throughout the design. Some of the signals around the IC change between 8mil and 10mil. The VDD trace changes from 15mil to 20mil  at C2 when a 20mil width could work for the entire trace.

3) Spec sheet specifies the use of the Sparkfun-2-layer-STANDARD.dru, the DRU being used in the design is Sparkfun-2-layer-TIGHT.dru.

4) Per the spec. sheet, the goal of this design is to create a single IC 9dof that has a smaller footprint than our current LSM9DS1 Breakout in order to allow usage in applications that require a smaller device because of size and space constraints. Based on the goal of the product, I think that we should shrink this board down even more (smaller dimensions) with some tight trace work. This would add to the value and usability of the board, as well as validate the use of the tight dru.

awende, 2016-05-26:
1) Bumping up to v20 was intentional. Given that the board is so different than v15, It should be bumped up to 2.0.

2) Any pin connected to the LSM9DS1 needs to be smaller than 10mil to avoid clearance issues. After closer inspection, the 15mil traces can be bumped back up to 20mil from VDD to C2.

3) It will need to be upgraded to Sparkfun-2-layer-TIGHT.dru.

4) Spec says to maintain at least the same board size as previous version. v15 is 0.4" x 1.35". The new design dropped the dimensions down to 0.4" x 1.0". However, in the updated design, I was able to shave off 100mil and bring the overall length to 0.9".

ericorosel, 2016-05-26:
(1) Sounds good on v20, I assume the plan is to then go to v21 for reds?

(2) The trace connecting to the LSM between C5 and the C1 pin on the chip is 10 mil, not 8 mil

(3) Noted, thanks

(4) Awesome, I really think that even shaving off that 100 mil will add to the value of this board! Thanks Alex

ericorosel, 2016-05-26:
(2) continued... One of the VDD traces entering the IC has a 9 mil width segment where the trace hits the IC pad

awende, 2016-05-26:
Fixed trace widths issue.

Closed 2016-05-26.

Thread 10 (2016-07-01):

v21 QC Checklist Review

ericorosel, 2016-07-01:
Only 1 issue: Per Bob's request, can we move the micro-fiducial by the capacitor from (0.200, 0.035) to somewhere around (0.325, 0.035).

awende, 2016-07-01:
fixed.

Closed 2016-07-01.

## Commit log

2014-05-28 Brd/Sch file(s) upload
    [9DoF_Sensor_Stick.brd, 9DoF_Sensor_Stick.sch]
2014-06-02 Computer Change
    [9DoF_Sensor_Stick.brd, 9DoF_Sensor_Stick.sch]
2014-06-02 comp change
    [9DoF_Sensor_Stick.brd]
2015-04-03 Adding in git files, updating to current boards on SF, cleaning up README
    [9DoF_Sensor_Stick.brd, SparkFun_9DoF_Sensor_Stick.brd, SparkFun_9DoF_Sensor_Stick.sch]
2016-01-06 created larger v15a panel
    [SparkFun_9DoF_Sensor_Stick_Panel_v15a.brd]
2016-05-20 2.0 Changes
    - Replaces all three 3-axis sensors with single chip solution (LSM9DS1).
    - Reduced board length from 1.3" to 1.0"
    - ±2/±4/±8/±16 g linear acceleration full scale
    - ±4/±8/±12/±16 gauss magnetic full scale
    - ±245/±500/±2000 dps angular rate full scale
    [9DoF_Sensor_Stick.brd, 9DoF_Sensor_Stick.sch, SparkFun_9DoF_Sensor_Stick.brd]
2016-05-23 Updating minor silk changes
    [9DoF_Sensor_Stick.brd]
2016-05-26 QC Fixes
    -Updated VDD trace width to 20mil throughout.
    -Reduced overall length from 1.0" to 0.9".
    [9DoF_Sensor_Stick.brd]
2016-05-26 Fixing Trace Widths
    All traces entering the IC are now the same size.
    [9DoF_Sensor_Stick.brd]
2016-06-30 v20 Changes
    - Switch to micro fiducials for better clearances.
    - Changed default I2C addresses to ox1E and 0x6B to match example code
    for LSM9DS1 Breakout.
    - Moved "v20" bottom copper text to clear bottom silk
    [9DoF_Sensor_Stick.brd, 9DoF_Sensor_Stick.sch]
2016-06-30 Changed visible layer settings
    [9DoF_Sensor_Stick.brd]
2016-06-30 V21 Changes
    Changes since initial v20:
    - Switched to micro fiducials for better clearances
    - Changed default I2C addresses to 0x1E and 0x6B to match LSM9DS1
    breakout board example code
    - Moved version text on bottom copper to clear the bottom silk
    [9DoF_Sensor_Stick.brd, 9DoF_Sensor_Stick.sch]
2016-06-30 Approved DRC Errors
    Approving overlap errors for jumpers
    [9DoF_Sensor_Stick.brd]
2016-07-01 Moved fiducial away from C3
    [9DoF_Sensor_Stick.brd]
2016-07-06 Created panel v21
    [13371_9DoF_Sensor_Stick_panel_v21.brd, SparkFun_9DoF_Sensor_Stick_Panel_v15a.brd]
2016-07-27 Updating files names to follow standard
    [SparkFun_9DoF_Sensor_Stick.brd, SparkFun_9DoF_Sensor_Stick.sch]
2016-08-11 Updating Readme
    Updated description with current sensor used and product dimensions
2016-08-11 Removed old sensors from Readme

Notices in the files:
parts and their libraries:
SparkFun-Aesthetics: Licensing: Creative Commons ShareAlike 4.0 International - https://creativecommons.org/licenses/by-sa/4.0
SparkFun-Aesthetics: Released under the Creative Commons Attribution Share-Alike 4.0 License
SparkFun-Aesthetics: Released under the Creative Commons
